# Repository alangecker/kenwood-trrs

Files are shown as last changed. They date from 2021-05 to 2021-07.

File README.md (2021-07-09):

# Kenwood TRRS Adapter
A tiny board, which allows using Kenwood headsets on smartphones, including the Push-To-Talk functionality.

Adapters with headsets

Assembled PCB

## Schematic
Schematic

## Bill of Materials
| Qty | Ident | Part | Notes
|----:|---:|---|---
| 1 | J2 | 2.5mm Jack PJ-211A |
| 1 | J3 | 3.5mm Jack PJ-313 | 
| 1 | J1 | 4-pin 3.5mm Jack Cable | cut in half
| 1 | Q1 | AO3400 N-Channel MOSFET  | or BSS138
| 1 | C1 | 100uF 6.3V RM2 5.0mm Elco
| 1 | R1,R5 | Resistor 100kΩ 0805
| 1 | R4 | Resistor 2MΩ 0805
| 2 | R2,R3 | Resistor 20Ω 0805
| 1 | | Heat shrink tube

## License


To the extent possible under law, Andreas Langecker has waived all copyright and related or neighboring rights to kenwood-trrs. This work is published from: Germany

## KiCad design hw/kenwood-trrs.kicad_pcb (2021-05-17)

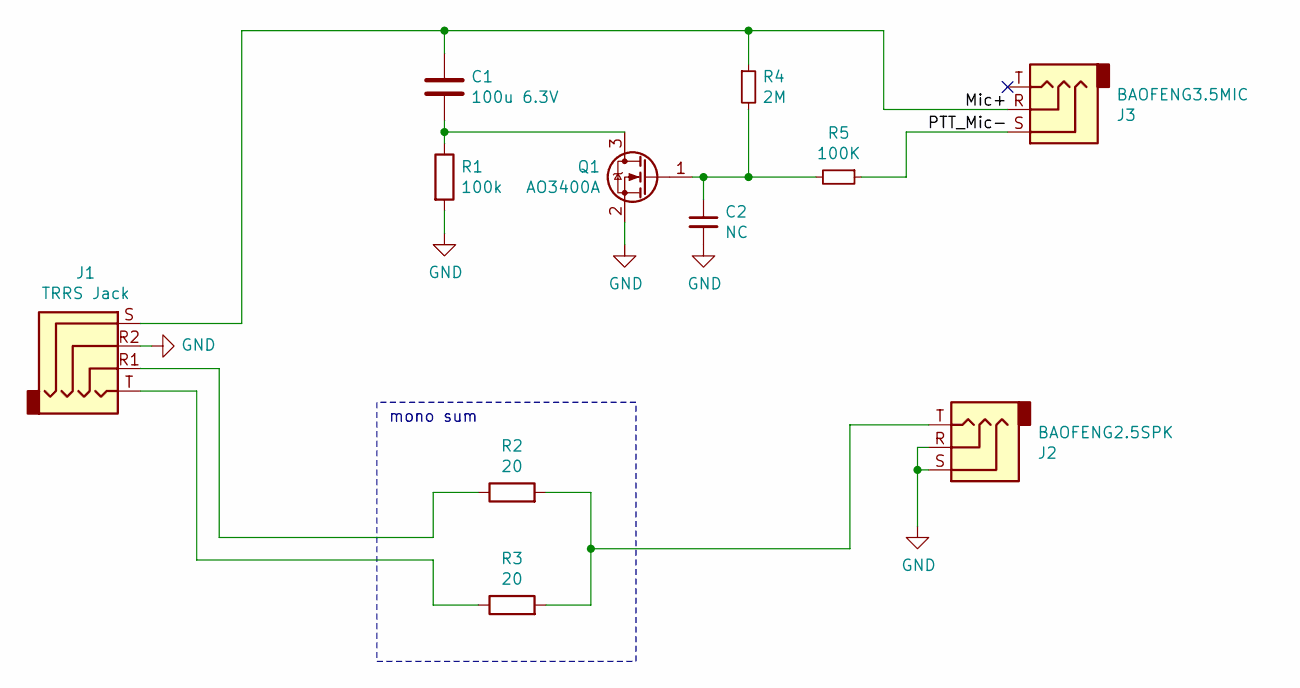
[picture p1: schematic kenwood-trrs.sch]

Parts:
C1: 100u 6.3V; CP_Radial_D5.0mm_P2.00mm
C2: NC; C_0805_2012Metric
J1: TRRS Jack; TRRS-Pins
J2: BAOFENG2.5SPK; PJ-211A
J3: BAOFENG3.5MIC; PJ-313-TH
Q1: AO3400A; SOT-23_Handsoldering
R1: 100k; R_0805_2012Metric_Pad1.20x1.40mm_HandSolder
R2, R3: 20; R_0805_2012Metric_Pad1.15x1.40mm_HandSolder
R4: 2M; R_0805_2012Metric_Pad1.20x1.40mm_HandSolder
R5: 100K; R_0805_2012Metric_Pad1.20x1.40mm_HandSolder

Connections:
/Mic+: C1.1, J1.S, J3.R, R4.1
/PTT_Mic-: J3.S, R5.1
GND: C2.2, J1.R2, J2.R, J2.S, Q1.2 (S), R1.2
unnamed: C1.2, Q1.3 (D), R1.1
unnamed: C2.1, Q1.1 (G), R4.2, R5.2
unnamed: J1.R1, R2.1
unnamed: J1.T, R3.1
unnamed: J2.T, R2.2, R3.2

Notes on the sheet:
mono sum

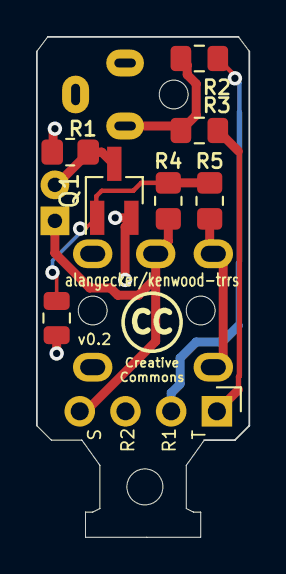
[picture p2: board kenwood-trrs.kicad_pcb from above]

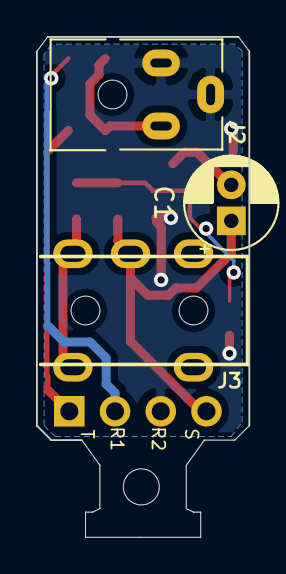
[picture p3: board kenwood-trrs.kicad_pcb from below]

Board: 2 copper layers, 11.8 x 27.8 mm, 11 parts (3 on the bottom side), 8 nets.

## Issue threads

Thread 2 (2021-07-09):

Mic detection unreliable for some Headsets

alangecker, 2021-07-09:
I have one headset here (Retevis brand) with a lower mic resistance (~1 kΩ). Sometimes (maybe 1 out of 4) the laptop or smartphone doesn't detect the microphone / assumes there is a 3-pin jack connected.

Putting a 500Ω resistor in series in front of the 3.5MIC seems to improve the reliability, but still not perfect.

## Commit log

2020-11-28 fixed jack footprints
    [kenwood-trrs.kicad_pcb]
2021-05-01 v0.1 gerber files
    [kenwood-trrs-B_Cu.gbr, kenwood-trrs-B_Mask.gbr, kenwood-trrs-B_Paste.gbr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]
2021-05-01 new version with different muting mechanism
    [kenwood-trrs.kicad_pcb, kenwood-trrs.sch]
2021-05-17 version 0.2
    [kenwood-trrs-B_Cu.gbr, kenwood-trrs-B_Mask.gbr, kenwood-trrs-B_Paste.gbr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]

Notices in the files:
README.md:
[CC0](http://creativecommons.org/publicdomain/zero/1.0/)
